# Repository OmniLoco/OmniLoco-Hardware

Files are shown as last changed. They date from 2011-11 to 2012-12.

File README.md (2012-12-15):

OmniLoco Hardware
=================

The official repository for all of the hardware used by and created for the OmniLoco
project.

Repository Contents
-------------------

### Top Level

* OmniRotor -- Sources for the OmniRotor platform, a sophisticated autonomous aircraft controller.
* Library -- Script files for individual EAGLE packages, symbols and devices. See below for more
information.

### Tools

* OmniRotor_PogoPlate -- Used for the automated programming and testing of production OmniRotor devices.

EAGLE Library
-------------
The EAGLE library used for the OmniLoco project has been split up into individual package,
symbol and device script files. This is done so git can track the changes of each individual
part of the library, rather than simply tracking one monolithic binary file.

Exporting the library must be done before every commit which which includes changes to the
library. This process could be automated, although it's much easier to do it by hand for now.

### Building the library from this repo
1. Open a new library (or open an existing OmniLoco library)
2. Run the lbrbuild.ulp script (located in the `Library` directory)
3. Point to the generated (or downloaded from git) `librarydefaults.scr` when prompted
4. All the packages/devices/symbols are added to the new/existing library

### Exporting the library after making changes
If you are on Windows and using EAGLE 6.3.0 you can use the `Library/_dump_library.bat` script

1. Open the OmniLoco library
2. File > Export > Script (This will generate one large script with all the devices in it)
3. Save it to the `Library` directory as `_full_library.scr`
4. Run the lbrdump.ulp script (located in the `Library` directory)
5. Open the exported library file (`_full_library.scr` from step 3)

The method for exporting and building an EAGLE library using script files is adapted from 
[DangerousPrototypes][1].

Contributing
------------

1. Fork it.
2. Create a branch (`git checkout -b my_hardware`)
3. Commit your changes (`git commit -am "Added Awesome Changes"`)
4. Push to the branch (`git push origin my_hardware`)
5. Create an issue with a link to your branch, or submit a pull request
6. Enjoy a refreshing beverage and wait

License
-------
All OmniLoco hardware is open source and compliant with the [Open Source Hardware Definition][2].

Copyright (c) 2012 by the OmniLoco Foundation. This work is made available under the terms of the Creative Commons Attribution-ShareAlike 3.0 license, http://creativecommons.org/licenses/by-sa/3.0/.

Open Source Hardware


[1]: http://dangerousprototypes.com/docs/Dangerous_Prototypes_Cadsoft_Eagle_parts_library
[2]: http://freedomdefined.org/OSHW#Open_Source_Hardware_.28OSHW.29_Definition_1.0

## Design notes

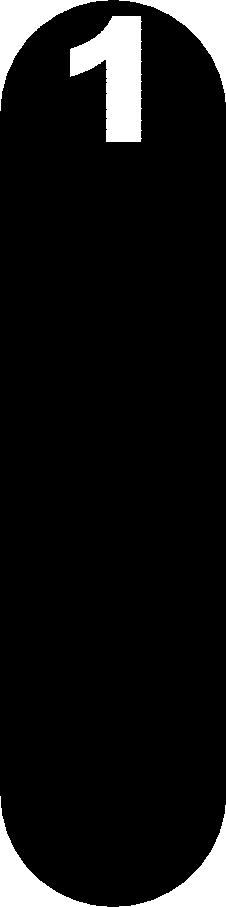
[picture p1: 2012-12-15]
OmniRotor/Artwork/servo-pin-1.bmp

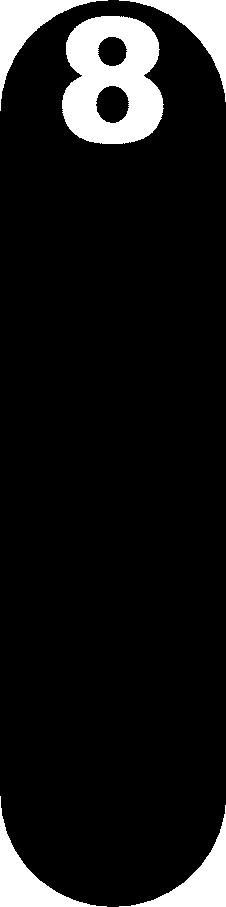
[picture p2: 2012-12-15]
OmniRotor/Artwork/servo-pin-8.bmp

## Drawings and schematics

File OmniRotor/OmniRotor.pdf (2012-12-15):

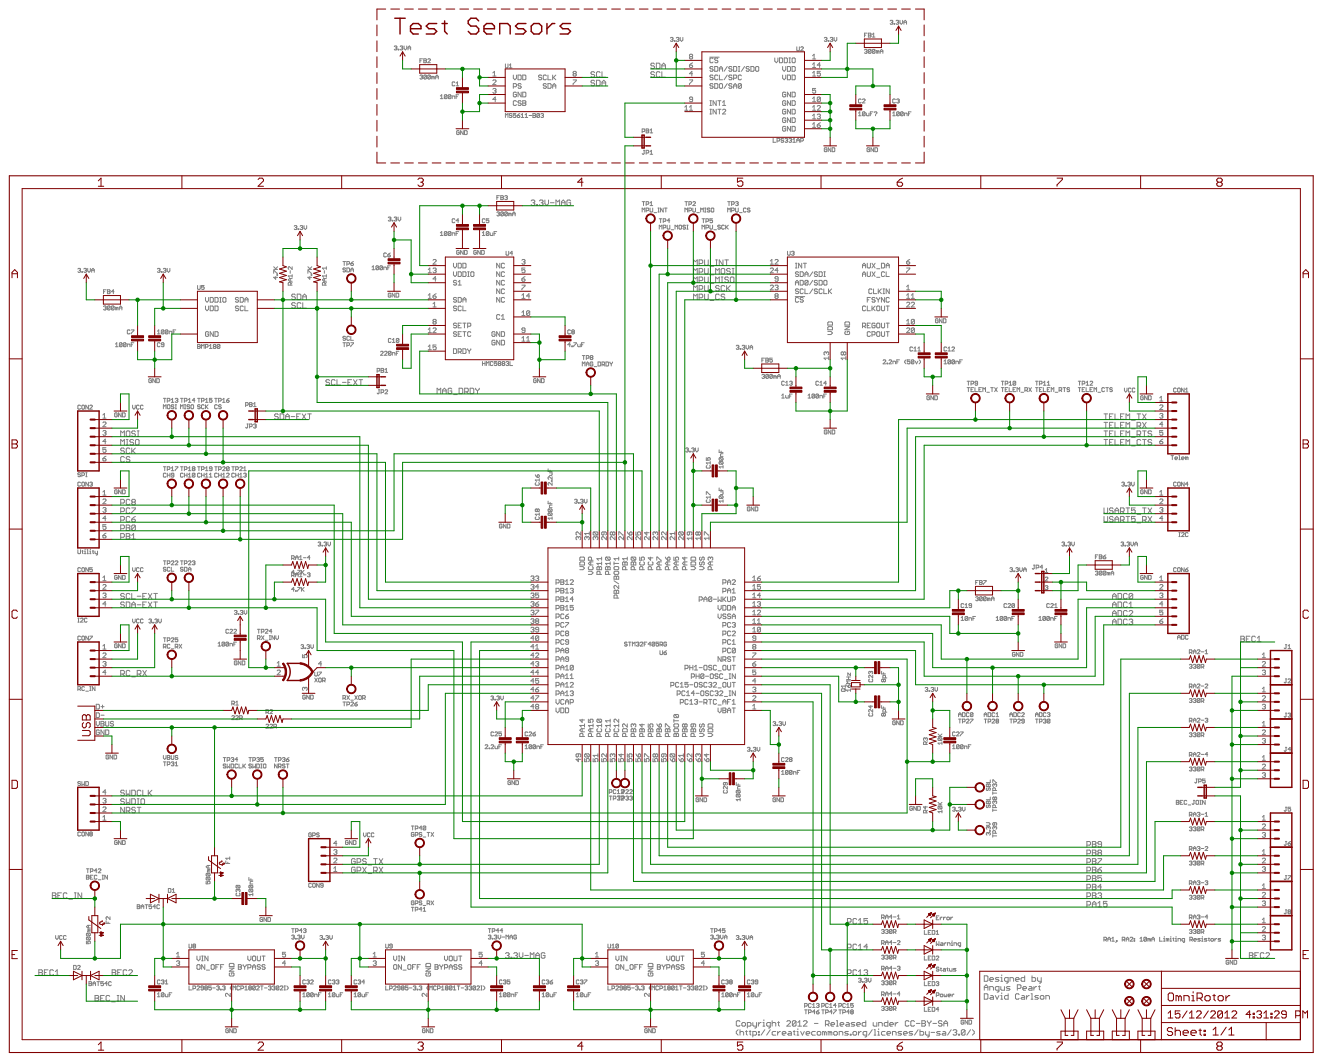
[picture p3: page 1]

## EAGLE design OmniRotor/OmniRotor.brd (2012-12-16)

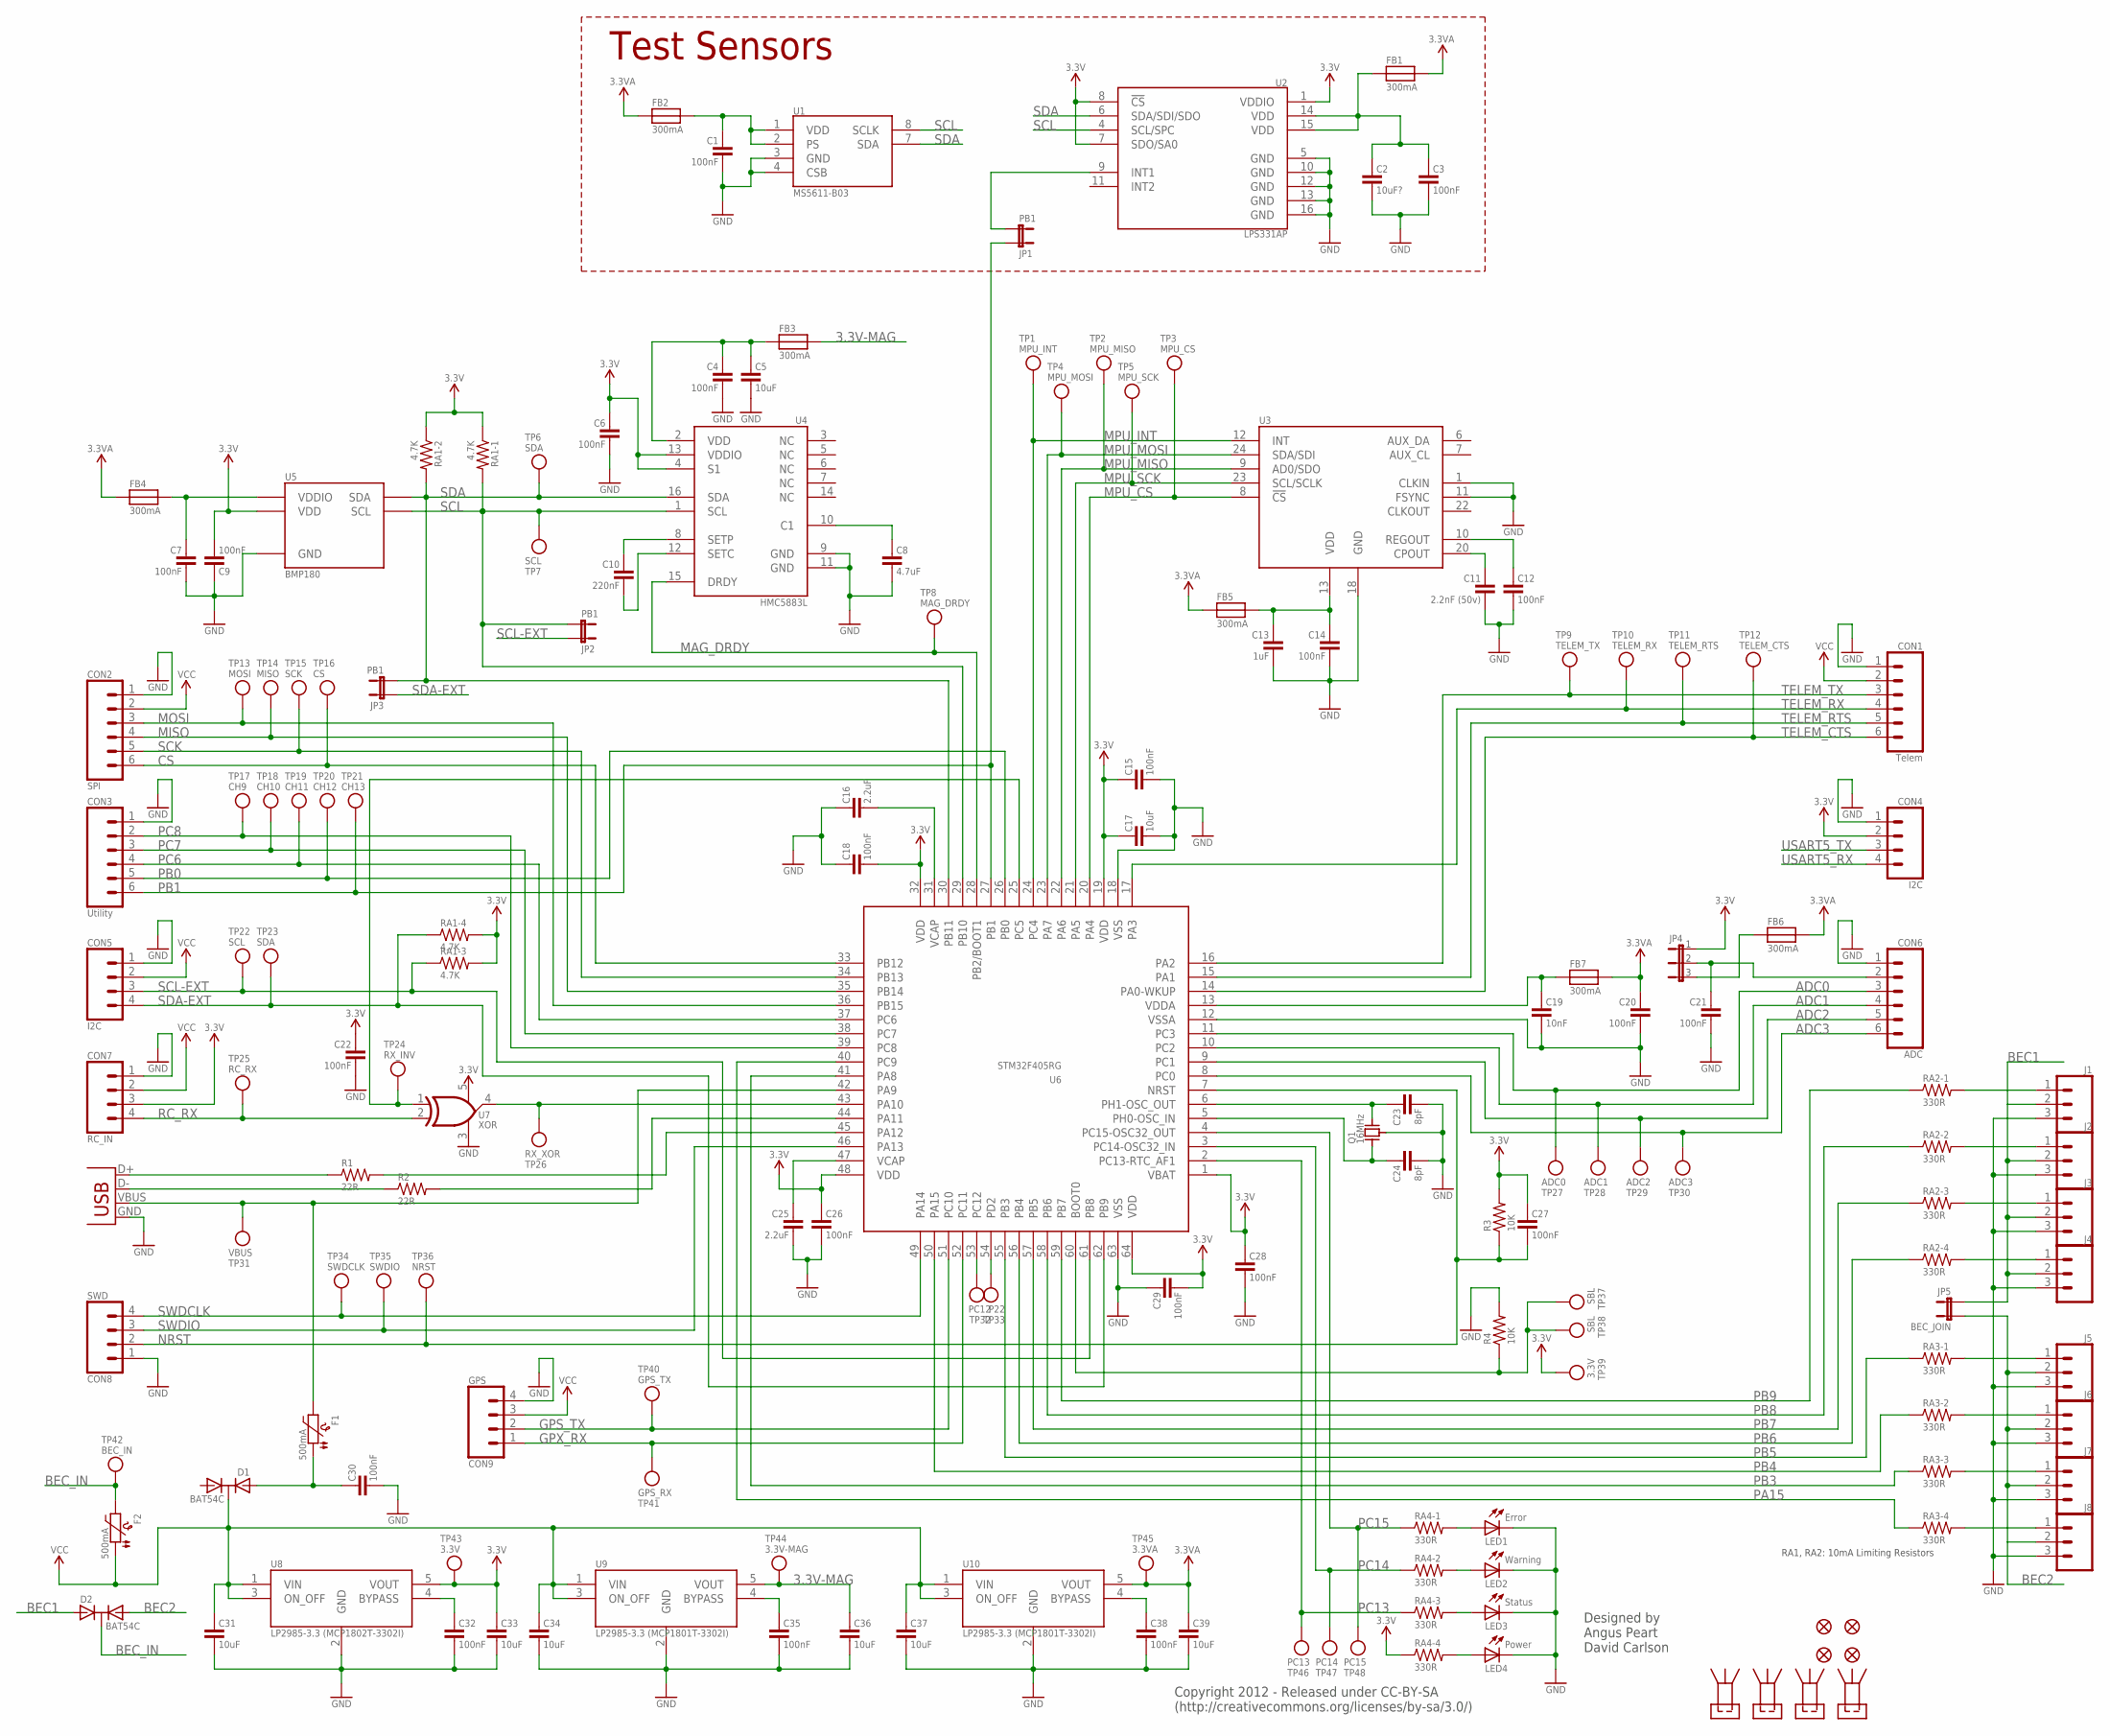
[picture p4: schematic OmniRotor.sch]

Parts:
C1, C3, C4, C6, C7, C9, C12, C14, C15, C18, C20, C21, C22, C26, C27, C28, C29, C30, C32, C35, C38: 100nF; 0402-CAP@1
C2: 10uF?; 0603@1
C5: 10uF; 0805@1
C8: 4.7uF; 0603@1
C10: 220nF; 0402-CAP@1
C11: 2.2nF (50v); 0402-CAP@1
C13: 1uF; 0603@1
C16, C25: 2.2uF; 0603@1
C17, C31, C33, C34, C36, C37, C39: 10uF; 0805
C19: 10nF; 0402-CAP@1
C23, C24: 8pF; 0402-CAP@1
CON1: Telem; SM06B-SRSS-TB
CON2: SPI; SM06B-SRSS-TB
CON3: Utility; SM06B-SRSS-TB
CON4, CON5: I2C; SM04B-SRSS-TB
CON6: ADC; SM06B-SRSS-TB
CON7: RC_IN; SM04B-SRSS-TB
CON8: SWD; BM04B-SRSS-TB
CON9: GPS; SM04B-SRSS-TB
D1, D2: BAT54C; SOT23
F1, F2: 500mA; 1210-PTC
FB1, FB2, FB3, FB4, FB5, FB6, FB7: 300mA; 0603
FID1, FID2, FID3, FID4: FIDUCIAL1X2.5; FIDUCIAL-1X2.5
J1, J2, J3, J4, J5, J6, J7, J8: M03PTH; 1X03
JP1, JP2, JP3: PB1; SJ_2_NO
JP4: JUMPER-31-2; SJ_3_PASTE1&2
JP5: BEC_JOIN; SJ_2_NO
LED1: Error; 0603_LED
LED2: Warning; 0603_LED
LED3: Status; 0603_LED
LED4: Power; 0603_LED
LP1, LP2, LP3, LP4: LIGHTPIPE; VLP-LIGHTPIPES
Q1: 16MHz; CRYSTAL_3-2X2-5
R1, R2: 22R; 0402-RES
R3, R4: 10K; 0402-RES
RA1: 4.7K; 1206-ARRAY
RA2, RA3, RA4: 330R; 1206-ARRAY
TP1: MPU_INT; TESTPOINT_ROUND_0.7MM
TP2: MPU_MISO; TESTPOINT_ROUND_0.7MM
TP3: MPU_CS; TESTPOINT_ROUND_0.7MM
TP4: MPU_MOSI; TESTPOINT_ROUND_0.7MM
TP5: MPU_SCK; TESTPOINT_ROUND_0.7MM
TP6, TP23: SDA; TESTPOINT_ROUND_0.7MM
TP7, TP22: SCL; TESTPOINT_ROUND_0.7MM
TP8: MAG_DRDY; TESTPOINT_ROUND_0.7MM
TP9: TELEM_TX; TESTPOINT_ROUND_0.7MM
TP10: TELEM_RX; TESTPOINT_ROUND_0.7MM
TP11: TELEM_RTS; TESTPOINT_ROUND_0.7MM
TP12: TELEM_CTS; TESTPOINT_ROUND_0.7MM
TP13: MOSI; TESTPOINT_ROUND_0.7MM
TP14: MISO; TESTPOINT_ROUND_0.7MM
TP15: SCK; TESTPOINT_ROUND_0.7MM
TP16: CS; TESTPOINT_ROUND_0.7MM
TP17: CH9; TESTPOINT_ROUND_0.7MM
TP18: CH10; TESTPOINT_ROUND_0.7MM
TP19: CH11; TESTPOINT_ROUND_0.7MM
TP20: CH12; TESTPOINT_ROUND_0.7MM
TP21: CH13; TESTPOINT_ROUND_0.7MM
TP24: RX_INV; TESTPOINT_ROUND_0.7MM
TP25: RC_RX; TESTPOINT_ROUND_0.7MM
TP26: RX_XOR; TESTPOINT_ROUND_0.7MM
TP27: ADC0; TESTPOINT_ROUND_0.7MM
TP28: ADC1; TESTPOINT_ROUND_0.7MM
TP29: ADC2; TESTPOINT_ROUND_0.7MM
TP30: ADC3; TESTPOINT_ROUND_0.7MM
TP31: VBUS; TESTPOINT_ROUND_0.7MM
TP32: PC12; TESTPOINT_ROUND_0.7MM
TP33: P22; TESTPOINT_ROUND_0.7MM
TP34: SWDCLK; TESTPOINT_ROUND_0.7MM
TP35: SWDIO; TESTPOINT_ROUND_0.7MM
TP36: NRST; TESTPOINT_ROUND_0.7MM
TP37: SBL; TESTPOINT_ROUND_1MM
TP38: SBL; TESTPOINT_ROUND_1.5MM
TP39: 3.3V; TESTPOINT_ROUND_1.5MM
TP40: GPS_TX; TESTPOINT_ROUND_0.7MM
TP41: GPS_RX; TESTPOINT_ROUND_0.7MM
TP42: BEC_IN; TESTPOINT_ROUND_0.7MM
TP43: 3.3V; TESTPOINT_ROUND_0.7MM
TP44: 3.3V-MAG; TESTPOINT_ROUND_0.7MM
TP45: 3.3VA; TESTPOINT_ROUND_0.7MM
TP46: PC13; TESTPOINT_ROUND_0.7MM
TP47: PC14; TESTPOINT_ROUND_0.7MM
TP48: PC15; TESTPOINT_ROUND_0.7MM
U1: MS5611-B03; MS5611
U2: LPS331AP; HCLGA-16L
U3: MPU6000; QFN-24
U4: HMC5883L; 16LPCC
U5: BMP180
U6: STM32F405RG; LQFP64
U7: XOR; SC-70-5
U8: LP2985-3.3 (MCP1802T-3302I); SOT-23-5
U9, U10: LP2985-3.3 (MCP1801T-3302I); SOT-23-5
USB1: USB-MICRO-B

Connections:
3.3V: C6.1, C9.2, C15.1, C17.1, C18.2, C22.1, C26.1, C27.1, C28.1, C29.2, C33.1, CON4.2, CON7.3, JP4.1, R3.2, RA1.A1 (1), RA1.B1 (1), RA1.C2 (2), RA1.D2 (2), RA4.D1 (1), TP39.1, TP43.1, U2.1 (VDDIO), U2.7 (SDO/SA0), U2.8 (!CS), U4.4 (S1), U4.13 (VDDIO), U5.2 (VDD), U6.1 (VBAT), U6.19 (VDD), U6.32 (VDD), U6.48 (VDD), U6.64 (VDD), U7.5 (VCC), U8.5 (VOUT)
3.3V-MAG: C36.1, FB3.2, TP44.1, U9.5 (VOUT)
3.3VA: C20.1, C39.1, FB1.2, FB2.1, FB4.1, FB5.1, FB6.2, FB7.2, TP45.1, U10.5 (VOUT)
ADC0: CON6.3, TP27.1, U6.11 (PC3)
ADC1: CON6.4, TP28.1, U6.10 (PC2)
ADC2: CON6.5, TP29.1, U6.9 (PC1)
ADC3: CON6.6, TP30.1, U6.8 (PC0)
BEC1: D2.1, J1.2, J2.2, J3.2, J4.2, JP5.1
BEC2: D2.2, J5.2, J6.2, J7.2, J8.2, JP5.2
BEC_IN: D2.3, F2.1, TP42.1
CS: CON2.6, TP16.1, U6.33 (PB12)
GND: C1.2, C2.2, C3.2, C4.2, C5.2, C6.2, C7.2, C8.2, C9.1, C11.2, C12.2, C13.2, C14.2, C15.2, C16.1, C17.2, C18.1, C19.2, C20.2, C21.2, C22.2, C23.2, C24.2, C25.2, C26.2, C28.2, C29.1, C30.2, C31.2, C32.2, C33.2, C34.2, C35.2, C36.2, C37.2, C38.2, C39.2, CON1.1, CON2.1, CON3.1, CON4.1, CON5.1, CON6.1, CON7.1, CON8.1, CON9.4, J1.3, J2.3, J3.3, J4.3, J5.3, J6.3, J7.3, J8.3, LED1.2 (C), LED2.2 (C), LED3.2 (C), LED4.2 (C), Q1.2 (GND), Q1.4 (GND), R4.2, U1.3 (GND), U1.4 (CSB), U2.5 (GND), U2.10 (GND), U2.12 (GND), U2.13 (GND), U2.16 (GND), U3.1 (CLKIN), U3.11 (FSYNC), U3.18 (GND), U4.9 (GND), U4.11 (GND), U5.7 (GND), U6.12 (VSSA), U6.18 (VSS), U6.63 (VSS), U7.3 (GND), U8.2 (GND), U9.2 (GND), U10.2 (GND), USB1.GND
GPS_TX: CON9.2, TP40.1, U6.51 (PC10)
GPX_RX: CON9.1, TP41.1, U6.52 (PC11)
MAG_DRDY: TP8.1, U4.15 (DRDY), U6.28 (PB2/BOOT1)
MISO: CON2.4, TP14.1, U6.35 (PB14)
MOSI: CON2.3, TP13.1, U6.36 (PB15)
MPU_CS: TP3.1, U3.8 (!CS!), U6.20 (PA4)
MPU_INT: TP1.1, U3.12 (INT), U6.24 (PC4)
MPU_MISO: TP2.1, U3.9 (AD0/SDO), U6.22 (PA6)
MPU_MOSI: TP4.1, U3.24 (SDA/SDI), U6.23 (PA7)
MPU_SCK: TP5.1, U3.23 (SCL/SCLK), U6.21 (PA5)
unnamed: C19.1, FB7.1, U6.13 (VDDA)
unnamed: C23.1, Q1.3 (2), U6.6 (PH1-OSC_OUT)
unnamed: C24.1, Q1.1, U6.5 (PH0-OSC_IN)
unnamed: C30.1, D1.1, F1.2
unnamed: C32.1, U8.4 (BYPASS)
unnamed: TP24.1, U6.25 (PC5), U7.1 (I0)
unnamed: C35.1, U9.4 (BYPASS)
unnamed: R1.1, USB1.D+
unnamed: R2.1, USB1.D-
unnamed: R2.2, U6.44 (PA11)
unnamed: R1.2, U6.45 (PA12)
unnamed: TP26.1, U6.43 (PA10), U7.4 (O)
unnamed: C10.1, U4.8 (SETP)
unnamed: C10.2, U4.12 (SETC)
unnamed: C13.1, C14.1, FB5.2, U3.13 (VDD)
unnamed: C8.1, U4.10 (C1)
unnamed: C21.1, CON6.2, JP4.2
unnamed: C2.1, C3.1, FB1.1, U2.14 (VDD), U2.15 (VDD)
unnamed: LED4.1 (A), RA4.D2 (2)
unnamed: LED3.1 (A), RA4.C2 (2)
unnamed: FB6.1, JP4.3
unnamed: LED2.1 (A), RA4.B2 (2)
unnamed: C11.1, U3.20 (CPOUT)
unnamed: C12.1, U3.10 (REGOUT)
unnamed: LED1.1 (A), RA4.A2 (2)
unnamed: J2.1, RA2.B2 (2)
unnamed: J3.1, RA2.C2 (2)
unnamed: J4.1, RA2.D2 (2)
unnamed: J1.1, RA2.A2 (2)
unnamed: J6.1, RA3.B2 (2)
unnamed: J7.1, RA3.C2 (2)
unnamed: J8.1, RA3.D2 (2)
unnamed: J5.1, RA3.A2 (2)
unnamed: JP1.2, U2.9 (INT1)
unnamed: R4.1, TP37.1, TP38.1, U6.60 (BOOT0)
unnamed: C38.1, U10.4 (BYPASS)
unnamed: C4.1, C5.1, FB3.1, U4.2 (VDD)
unnamed: C7.1, FB4.2, U5.3 (VDDIO)
unnamed: C1.1, FB2.2, U1.1 (VDD), U1.2 (PS)
NRST: C27.2, CON8.2, R3.1, TP36.1, U6.7 (NRST)
PA15: RA3.D1 (1), U6.40 (PC9)
PB0: CON3.5, TP20.1, U6.26 (PB0)
PB1: CON3.6, JP1.1, TP21.1, U6.27 (PB1)
PB3: RA3.C1 (1), U6.41 (PA8)
PB4: RA3.B1 (1), U6.50 (PA15)
PB5: RA3.A1 (1), U6.55 (PB3)
PB6: RA2.D1 (1), U6.56 (PB4)
PB7: RA2.C1 (1), U6.57 (PB5)
PB8: RA2.B1 (1), U6.58 (PB6)
PB9: RA2.A1 (1), U6.59 (PB7)
PC6: CON3.4, TP19.1, U6.37 (PC6)
PC7: CON3.3, TP18.1, U6.38 (PC7)
PC8: CON3.2, TP17.1, U6.39 (PC8)
PC13: RA4.C1 (1), TP46.1, U6.2 (PC13-RTC_AF1)
PC14: RA4.B1 (1), TP47.1, U6.3 (PC14-OSC32_IN)
PC15: RA4.A1 (1), TP48.1, U6.4 (PC15-OSC32_OUT)
RC_RX: CON7.4, TP25.1, U7.2 (I1)
SCK: CON2.5, TP15.1, U6.34 (PB13)
SCL: JP2.2, RA1.A2 (2), TP7.1, U1.8 (SCLK), U2.4 (SCL/SPC), U4.1 (SCL), U5.5 (SCL), U6.29 (PB10)
SCL-EXT: CON5.3, JP2.1, RA1.C1 (1), TP22.1, U6.61 (PB8)
SDA: JP3.2, RA1.B2 (2), TP6.1, U1.7 (SDA), U2.6 (SDA/SDI/SDO), U4.16 (SDA), U5.6 (SDA), U6.30 (PB11)
SDA-EXT: CON5.4, JP3.1, RA1.D1 (1), TP23.1, U6.62 (PB9)
SWDCLK: CON8.4, TP34.1, U6.49 (PA14)
SWDIO: CON8.3, TP35.1, U6.46 (PA13)
TELEM_CTS: CON1.6, TP12.1, U6.14 (PA0-WKUP)
TELEM_RTS: CON1.5, TP11.1, U6.15 (PA1)
TELEM_RX: CON1.4, TP10.1, U6.17 (PA3)
TELEM_TX: CON1.3, TP9.1, U6.16 (PA2)
USART5_RX: CON4.4, TP33.1, U6.54 (PD2)
USART5_TX: CON4.3, TP32.1, U6.53 (PC12)
VCAP@1: C16.2, U6.31 (VCAP)
VCAP@2: C25.1, U6.47 (VCAP)
VCC: C31.1, C34.1, C37.1, CON1.2, CON2.2, CON5.2, CON7.2, CON9.3, D1.3, F2.2, U8.1 (VIN), U8.3 (ON_OFF), U9.1 (VIN), U9.3 (ON_OFF), U10.1 (VIN), U10.3 (ON_OFF)
VUSB: F1.1, TP31.1, U6.42 (PA9), USB1.VBUS

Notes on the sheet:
RA1, RA2: 10mA Limiting Resistors
Test Sensors
Designed by Angus Peart David Carlson
Copyright 2012 - Released under CC-BY-SA (http://creativecommons.org/licenses/by-sa/3.0/)

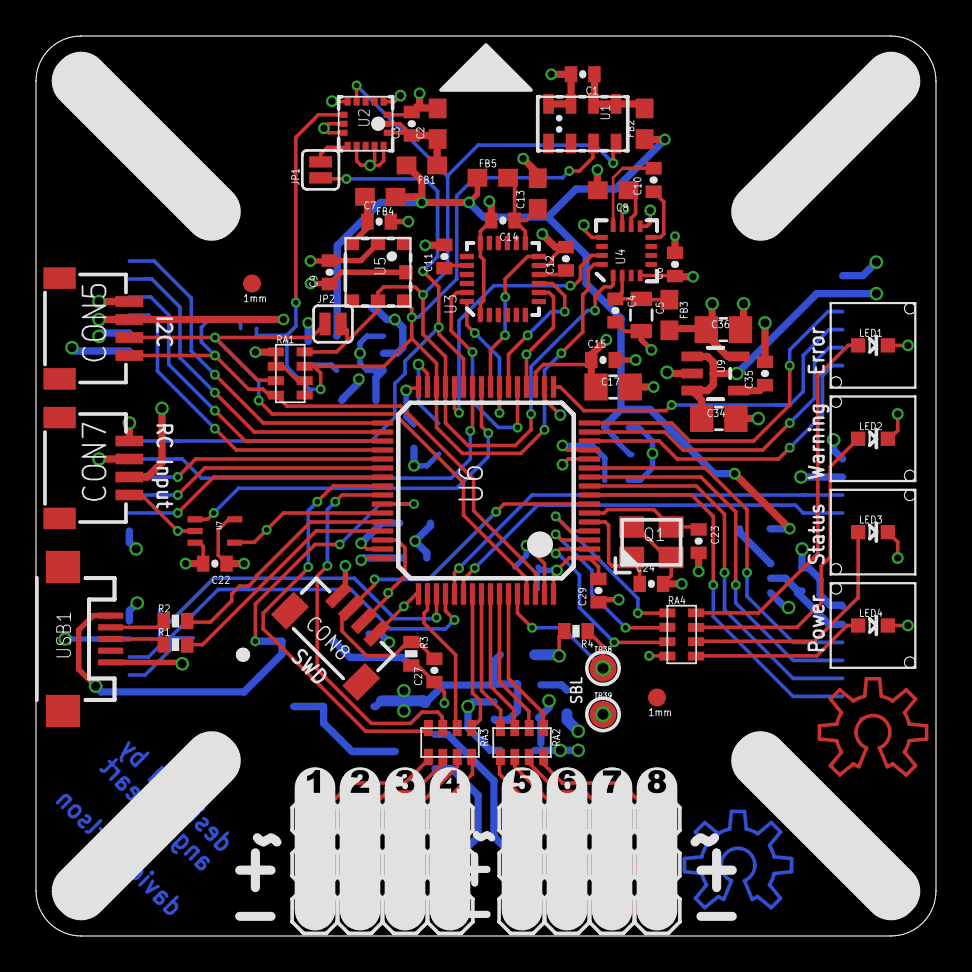
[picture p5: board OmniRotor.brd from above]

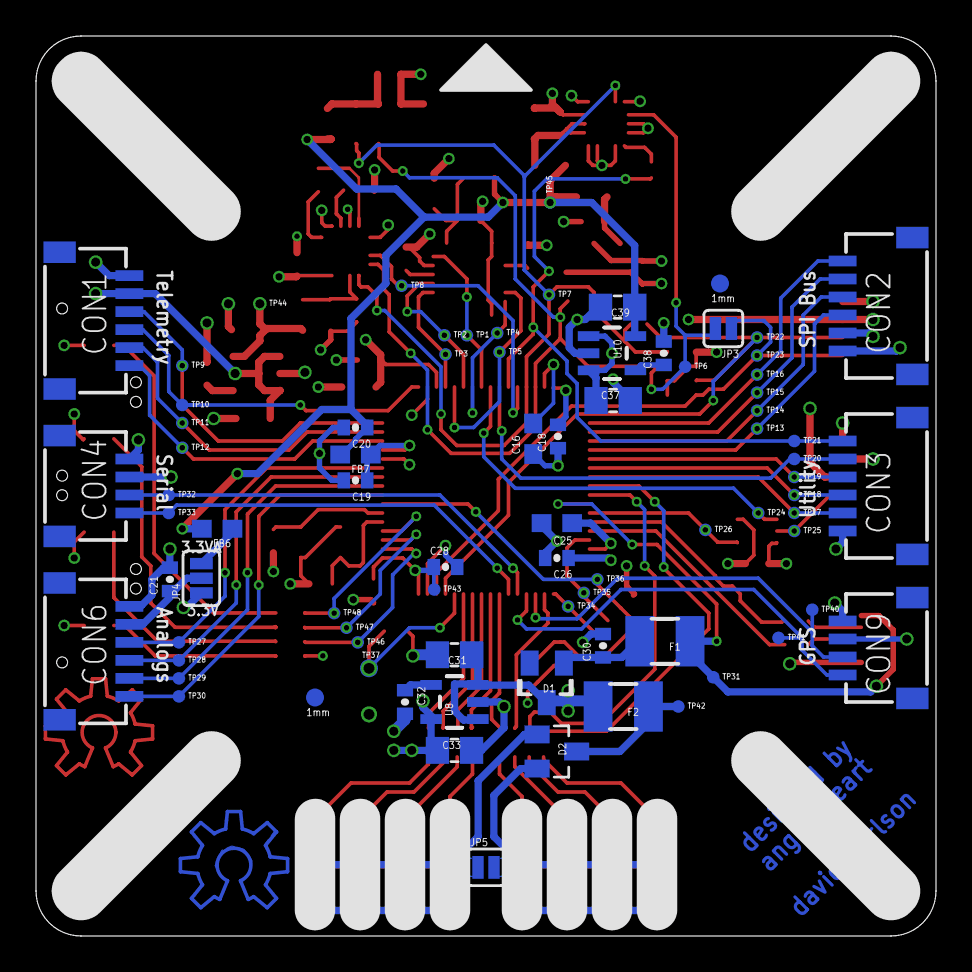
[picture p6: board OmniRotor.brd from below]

Board: 4 copper layers, 50.0 x 50.0 mm, 160 parts (80 on the bottom side), 96 nets.

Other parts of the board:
U$16: SILK-SERVO-1
U$24: SILK-SERVO-4
U$28: SILK-SERVO-3
U$31: SILK-SERVO-2
U$32: SILK-SERVO-5
U$33: SILK-SERVO-6
U$34: SILK-SERVO-7
U$35: SILK-SERVO-8

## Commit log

2011-10-15 Initial Commit. Added OmniRotor v1.0
    [OmniRotor-1_0.brd, OmniRotor-1_0.sch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]
2011-10-15 Removed invalid gerbers.
2011-10-15 Changes pressure sensor from BMP085 to newer BMP180. Minor silkscreen updates and added .gitignore file.
2011-10-15 Changes pressure sensor from BMP085 to newer BMP180. Minor silkscreen updates.
    [OmniRotor-1_0.brd, OmniRotor-1_0.sch]
2011-10-30 Fixed LED names on schematic. Added bCream gerbers.
2011-10-30 Added testpoints for pogopin programming.
    [OmniRotor-1_0.brd, OmniRotor-1_0.sch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]
2011-10-30 Added OmnoRotor_PogoPlate design, used in a production programming and testing tool.
    [OmniRotor_PogoPlate.brd, OmniRotor_PogoPlate.sch]
2011-10-30 Added TELEM_USART testpoints.
    [OmniRotor-1_0.brd, OmniRotor-1_0.sch, OmniRotor_PogoPlate.brd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]
2011-10-30 Added mechanical vision alignment fiducials.
    [OmniRotor-1_0.brd, OmniRotor-1_0.sch]
2011-10-30 Added EAGLE Library files and cleaned up schematic somewhat.
    [OmniRotor-1_0.brd, OmniRotor-1_0.sch]
2011-11-10 Updated Schematic/Board files to reflect changes in library. Note that some parts (such as STM32/CAPACITOR) use old definitions because of rename.
    [OmniRotor-1_0.brd, OmniRotor-1_0.sch]
2011-11-10 Updated 10uF Capacitors from 0603 to 0805 packages.
    [OmniRotor-1_0.brd, OmniRotor-1_0.sch]
2011-11-10 Switched crystal from 8MHz to 12MHz version.
    [OmniRotor-1_0.brd, OmniRotor-1_0.sch]
2011-11-10 Renamed schematic and board files by removing versioning. Git tags will now be used for versioning.
    [OmniRotor-v1.brd, OmniRotor-v1.sch]
2011-11-16 Added redundant BEC supply circuit. Added ADC connector voltage jumper with filtering. Components: Added; FB2, C34, C35, D2, C36; Removed; C27.
    [OmniRotor-v1.brd, OmniRotor-v1.sch]
2011-11-16 Changed LED to light-pipe footprints.
    [OmniRotor-v1.brd, OmniRotor-v1.sch]
2011-11-16 Updated OR pogoplate to reflect OR changes.
    [OmniRotor_PogoPlate.brd, OmniRotor_PogoPlate.sch]
2011-11-18 Added solder jumper to bridge BEC inputs for single BEC systems. Removed: C25, C36.
    [OmniRotor-v1.brd, OmniRotor-v1.sch]
2012-12-01 Q4 2012 Changes
    - Updated MPU3000 to MPU6000
    - Removed Accelerometer
    - Removed EEPROM
    - Added MAG3110 and LPS331AP (for testing and verification)
    - Updated silkscreen
    - Fixed some routing and internal ground planes
    - Fixed via tenting
    - Standardised on connector pinout power/ground pins
    - Changed LEDs to active high
    - Changed LEDs to lightpipe footprint type
    - Moved RHS connectors to inverse side to accommodate lightpipe
    footprints
    - Added many test-points, one to every connector IO and voltage rail
    - Reversed servo 1-8 numbering to be more logical (Right to Left)
    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
    [OmniRotor-v1.brd, OmniRotor-v1.sch]
2012-12-01 Renamed EAGLE files, removed version from filename.
    [OmniRotor.brd, OmniRotor.sch]
2012-12-06 Changed debug interface from JTAG to SWD.
    Frees up 2 GPIO. Also added pull-up and decoupling cap to reset line.
    [OmniRotor.brd, OmniRotor.sch]
2012-12-11 More updates for Q4 2012 production.
    - Added MS5611 pressure sensor
    - Removed MAG3110
    - Remapped some I/O pins
    - Added additional UART connector
    - Added Utility connector (PWM+ADC+SPI)
    - Cleaned up all routing
    - Moved magnetometer, fixed ground planes
    - Changed PTC to 1210 package
    - Re-aligned lightpipes
    - Remapped most servo IO for maximum flexibility in other peripherals
    - Replaced TX pin on RC Input connector with 3.3V, removed voltage
    select jumper
    - Changed crystal package and frequency
    - Added 2.5x3.2mm crystal footprint
    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
    [OmniRotor.brd, OmniRotor.sch]
2012-12-15 Board functional design done, silkscreen updated
    - Board routing and pin re-mapping complete
    - Started on silkscreen changes
    [OmniRotor.brd, OmniRotor.sch]
2012-12-16 Silkscreen and component footprint updates
    [OmniRotor.brd, OmniRotor.sch]
